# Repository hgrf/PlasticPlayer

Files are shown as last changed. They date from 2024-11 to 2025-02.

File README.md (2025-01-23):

# Plastic Player 3

This is a remake of [Plastic Player 2](https://brendandawes.com/projects/plasticplayer2) ([repo](https://github.com/brendandawes/PlasticPlayer)), an NFC based controller for Spotify. This isn't a step by step instructables style build guide but hopefully there's enough information here to build your own version. Knowledge of building stuff like this, soldering and understanding Linux, software compilation and the like would be good.

## System overview

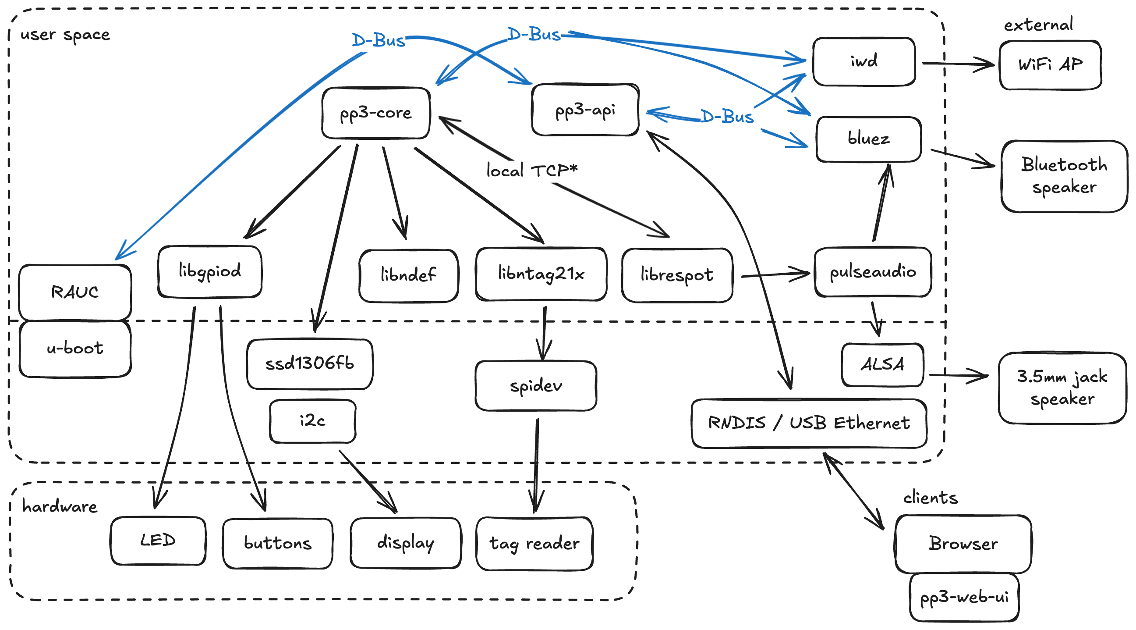
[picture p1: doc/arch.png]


*The TCP socket connection between pp3-core and librespot is a quick hack and should be replaced
by a clean D-Bus interface. [Spotifyd](https://github.com/Spotifyd/spotifyd) provides a D-Bus
media player interface and also uses `librespot` for playback, but it does not use an up-to-date
version of `librespot`...

## Materials

* **Raspberry Pi 4B** | [ CAD ](https://grabcad.com/library/raspberry-pi-4-model-b-1) | [ Amazon ](https://www.amazon.fr/dp/B07TGBLK33/)
* **128 x 64 I2C OLED**, [ CAD ](https://grabcad.com/library/arduino-0-91-0-96-inch-oled-1) | [ Amazon ](https://www.amazon.fr/dp/B0CN96XB5Y)
  NOTE: There are similar OLED modules with slightly different dimensions, e.g.:
  * https://grabcad.com/library/ssd1306-oled-display-128x64-1
  * https://grabcad.com/library/i2c-0-96-oled-ssd1306-display-1
  * https://grabcad.com/library/display-oled-ssd1306-de-0-96-1
  * Even when ordering twice from the same supplier (Amazon Link above), you can end up with 21 vs. 22 mm horizontal screw spacing
* [ **Joy-IT RFID module** ](https://joy-it.net/en/products/SBC-RFID-RC522) | [ CAD ](https://grabcad.com/library/rfid-rc5222-1) | [ Amazon ](https://www.amazon.fr/dp/B07B3N1WTL)
  * _TODO_: here too it seems the screw spacing does not 100% correspond
* 2 x **Sanwa Arcade Buttons** | [ CAD ](https://grabcad.com/library/sanwa-obsf-24-arcade-button-1) | [ Amazon ](https://www.amazon.fr/dp/B075DCB7LT)
* **NFC Stickers** | [ Amazon ](https://www.amazon.fr/dp/B0BVFM8YVD)
* 3D printed enclosure and slides (available on this repo)
* **screws**
  * display screws: 4x M1.7*5 PA Phillips self-tapping screw
  * Raspberry Pi screws: 4x M2*4
  * RF tag reader screw: 2x M3*4
  * case screws: 3x M3*8
* **magnets**
  * 2x Neodyme magnet 6x2 mm
  * 2x Neodyme magnet 3x2 mm
* **rubber feet** | e.g. cylindrical 8.5x2 mm [Amazon](https://www.amazon.fr/dp/B09KTCFC1L)
* a Spotify Premium account

## Hardware

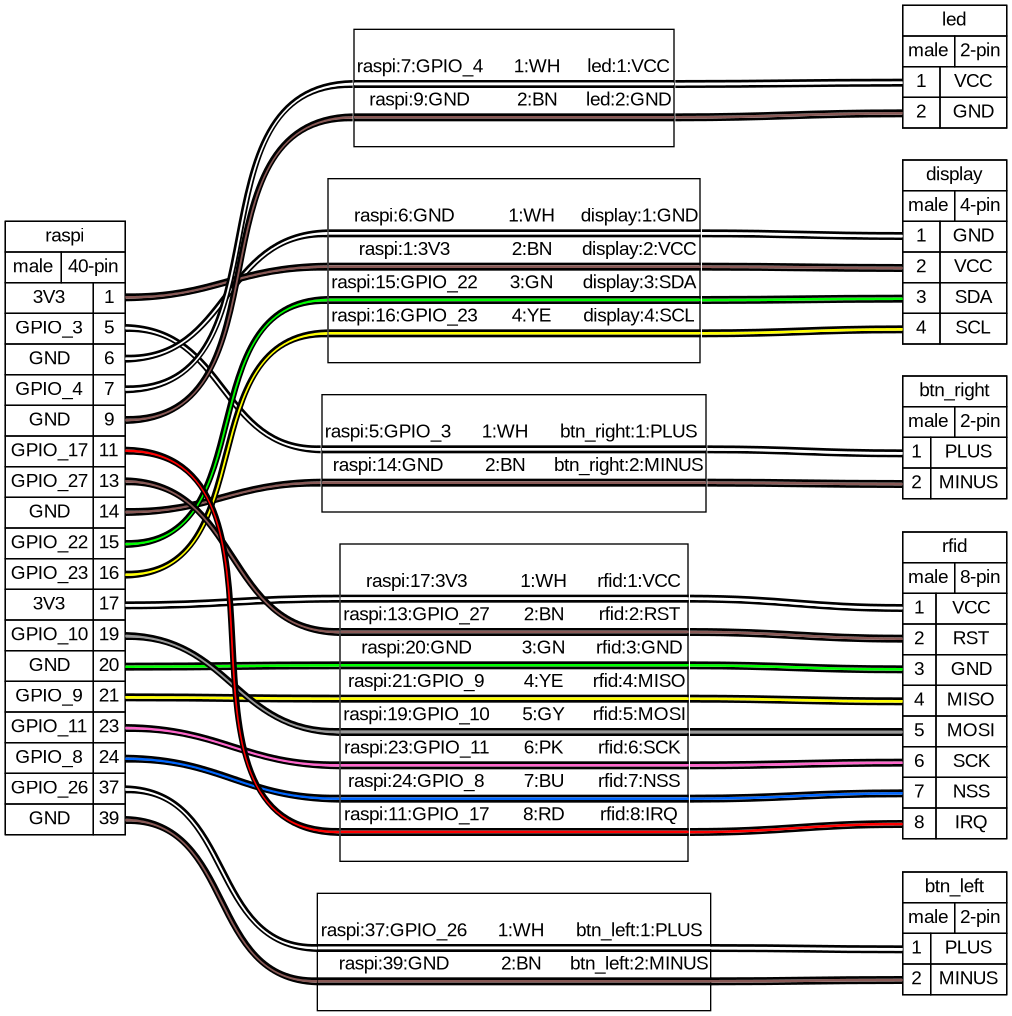
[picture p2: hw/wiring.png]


## Building

### Setting up buildroot

```sh
docker build -t buildroot docker
docker run --rm -it -v ${PWD}:/workspace buildroot bash
make -C buildroot/ BR2_EXTERNAL=../br-external O=../output raspberrypi4-64-rauc_defconfig
cd br-external && ./openssl-ca.sh
```

The last line generates an OpenSSL certificate and signing key for RAUC firmware updates.
Note that you can only use the firmware update feature if the new firmware was signed with
the same key as the old firmware.

If you want to connect to the Plastic Player via SSH, put your public key in the `ssh-keys`
directory.

### Building on macOS

On macOS, you might run into two problems:

* `chmod: changing permissions of ...: Permission denied`: In Docker Desktop, go to Settings
  -> General -> Choose file sharing implementation for your containers -> gRPC FUSE (instead
  of VirtioFS)
* `undefined reference to __lll_lock_wake_private` and possibly other build errors in glibc:
  Put your build folder in a case-sensitive file system, see:
  * https://brianboyko.medium.com/a-case-sensitive-src-folder-for-mac-programmers-176cc82a3830
  * https://stackoverflow.com/questions/73417071/glibc-compilation-error-undefined-reference-to-lll-lock-wait-private
  * https://github.com/riscv-collab/riscv-gnu-toolchain/issues/742#issuecomment-1061055030

### Building the image

```sh
docker run --rm -it -v ${PWD}:/workspace buildroot bash
make -C output/ VERSION=<PUT VERSION HERE>
```

## Developing

### SSH config

```
Host pp3
    HostName 10.42.0.1
    User user
    IdentityFile ~/.ssh/id_ed25519
    StrictHostKeyChecking=no
    UserKnownHostsFile=/dev/null
```

### Syncing the web app

```sh
rsync --rsync-path="sudo rsync" -avh --delete web_ui/build/web/ pp3:/usr/html
```

## Appendix

### Wiring

```sh
docker run --rm -it -v ${PWD}:/workspace buildroot /venv/bin/wireviz -f p wiring.yml
```

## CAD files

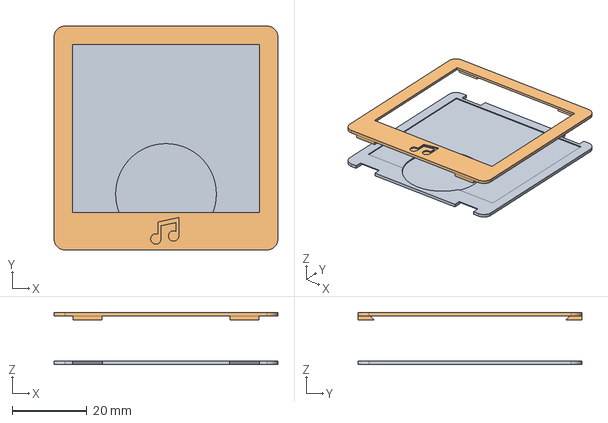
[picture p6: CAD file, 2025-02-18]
hw/plastic.FCStd
60.0 x 60.0 x 14.0 mm
Back
Front

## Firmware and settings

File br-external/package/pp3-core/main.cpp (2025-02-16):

#include <algorithm>
#include <cstdint>
#include <iostream>
#include <signal.h>

#include <ndef-lite/message.hpp>

#include "librespot.h"
#include "tagreader.h"
#include "ui.h"
#include "wifistatus.h"

static bool g_is_running = true;
static char stdout_buffer[1024];
static char stderr_buffer[1024];
static std::string g_current_uri;

static void signal_handler(int signum) {
    g_is_running = false;
}

static void load_uri(const std::string& uri) {
    const std::string base_uri = "https://open.spotify.com/";
    if (uri.substr(0, base_uri.length()) != base_uri) {
        std::cout << "URI does not start with " << base_uri << std::endl;
        return;
    }

    if (uri == g_current_uri) {
        return;
    }
    g_current_uri = uri;

    ui_led_on();
    std::string cmd = "load spotify:" + uri.substr(base_uri.length());
    std::replace(cmd.begin(), cmd.end(), '/', ':');
    std::cout << "cmd: " << cmd << std::endl;
    librespot_send_cmd(cmd.c_str(), false);
}

static void ndef_msg_cb(uint8_t *raw_msg, unsigned int len) {
    NDEFMessage msg;
    try {
        msg = NDEFMessage::from_bytes(std::vector<uint8_t>(raw_msg, raw_msg + len), 0);
    } catch (const std::exception& e) {
        std::cout << "failed to parse NDEF message: " << e.what() << std::endl;
        return;
    }

    std::cout << "NDEF message has " << msg.record_count() << " records" << std::endl;
    if (msg.record_count() > 0) {
        // c.f. https://github.com/hgrf/NDEF/commit/4c3133f6830fbe595c937db7a17c7a65eb487a82
        // c.f. https://github.com/hgrf/NDEF/commit/e035efd38d2deb2f6b94301faa5937c59c1dba61
        // c.f. https://www.oreilly.com/library/view/beginning-nfc/9781449324094/ch04.html
        // c.f. https://www.oreilly.com/library/view/beginning-nfc/9781449324094/apa.html
        // c.f. https://berlin.ccc.de/~starbug/felica/NFCForum-SmartPoster_RTD_1.0.pdf
        const auto &rec = msg.record(0);
        if (rec.type().name() == "U") {
            auto uri = msg.record(0).get_uri_protocol() + msg.record(0).get_uri();
            std::cout << "Record 1 URI: " << uri << std::endl;
            load_uri(uri);
        } else if (rec.type().name() == "Sp") {
            auto sp_msg = NDEFMessage::from_bytes(rec.payload(), 0);
            if (sp_msg.is_valid()) {
                std::cout << "Record 1 Smart Poster is valid and has " << sp_msg.record_count() << " records" << std::endl;
                if (sp_msg.record_count() > 0) {
                    const auto &sp_rec = sp_msg.record(0);
                    if (sp_rec.type().name() == "U") {
                        auto uri = sp_msg.record(0).get_uri_protocol() + sp_msg.record(0).get_uri();
                        std::cout << "Record 1 Smart Poster URI: " << uri << std::endl;
                        load_uri(uri);
                    } else {
                        std::cout << "Record 1 Smart Poster type: " << sp_rec.type().name() << std::endl;
                    }
                }
            }
        } else {
            std::cout << "Record 1 type: " << rec.type().name() << std::endl;
        }
    }
}

static void tag_removed_cb(void) {
    ui_led_off();
    g_current_uri.clear();
    librespot_send_cmd("pause", false);
}

int main(int argc, char *argv[]) {
    int res;

    signal(SIGINT, signal_handler);

    setvbuf(stdout, stdout_buffer, _IOLBF, sizeof(stdout_buffer));
    setvbuf(stderr, stderr_buffer, _IOLBF, sizeof(stderr_buffer));

    res = tag_reader_init(ndef_msg_cb, tag_removed_cb);
    if (res != 0) {
        return 1;
    }

    res = ui_init();
    if (res != 0) {
        tag_reader_deinit();
        return 1;
    }

    res = librespot_init();
    if (res != 0) {
        ui_deinit();
        tag_reader_deinit();
        return 1;
    }

    while(g_is_running) {
        ui_process();
    }

    librespot_deinit();

    ui_deinit();

    tag_reader_deinit();
    
    return 0;
}

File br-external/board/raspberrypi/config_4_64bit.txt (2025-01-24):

# For more options and information see
# http://rpf.io/configtxt
# Some settings may impact device functionality. See link above for details

# uncomment if you get no picture on HDMI for a default "safe" mode
#hdmi_safe=1

# uncomment the following to adjust overscan. Use positive numbers if console
# goes off screen, and negative if there is too much border
#overscan_left=16
#overscan_right=16
#overscan_top=16
#overscan_bottom=16

# uncomment to force a console size. By default it will be display's size minus
# overscan.
#framebuffer_width=1280
#framebuffer_height=720

# uncomment if hdmi display is not detected and composite is being output
#hdmi_force_hotplug=1

# uncomment to force a specific HDMI mode (this will force VGA)
#hdmi_group=1
#hdmi_mode=1

# uncomment to force a HDMI mode rather than DVI. This can make audio work in
# DMT (computer monitor) modes
#hdmi_drive=2

# uncomment to increase signal to HDMI, if you have interference, blanking, or
# no display
#config_hdmi_boost=4

# uncomment for composite PAL
#sdtv_mode=2

#uncomment to overclock the arm. 700 MHz is the default.
#arm_freq=800

# Uncomment some or all of these to enable the optional hardware interfaces
#dtparam=i2c_arm=on
#dtparam=i2s=on
#dtparam=spi=on

# Uncomment this to enable infrared communication.
#dtoverlay=gpio-ir,gpio_pin=17
#dtoverlay=gpio-ir-tx,gpio_pin=18

# Additional overlays and parameters are documented /boot/overlays/README

# Enable audio (loads snd_bcm2835)
dtparam=audio=on

# Automatically load overlays for detected cameras
camera_auto_detect=1

# Automatically load overlays for detected DSI displays
display_auto_detect=1

# Enable DRM VC4 V3D driver
dtoverlay=vc4-kms-v3d
max_framebuffers=2

# Disable compensation for displays with overscan
disable_overscan=1

[cm4]
# Enable host mode on the 2711 built-in XHCI USB controller.
# This line should be removed if the legacy DWC2 controller is required
# (e.g. for USB device mode) or if USB support is not required.
otg_mode=1

[all]

[pi4]
# Run as fast as firmware / board allows
arm_boost=1

[all]

# End of the default Raspberry Pi config.txt file from:
# https://github.com/RPi-Distro/pi-gen/blob/master/stage1/00-boot-files/files/config.txt

# Load U-Boot instead of Linux
kernel=u-boot.bin

# Enable 64-bit support
arm_64bit=1

# fixes rpi (3B, 3B+, 3A+, 4B and Zero W) ttyAMA0 serial console
dtoverlay=miniuart-bt

# Enable watchdog, system will reset if U-Boot and Linux do not boot within 16 seconds
# Requires fairly recent RPi Firmware:
# https://github.com/raspberrypi/firmware/issues/1651
# Comment this line if you expect to be able to use the U-Boot command prompt!
dtparam=watchdog

gpio=4=op,dh

# Enable early debugging info
uart_2ndstage=1

dtoverlay=i2c-gpio,i2c_gpio_sda=22,i2c_gpio_scl=23

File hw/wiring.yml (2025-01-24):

connectors:
  raspi:
    subtype: male
    pincount: 40
    pins:      [  1,      5,   6,      7,   9,      11,      13,  14,      15,      16,  17,      19,  20,     21,      23,     24,      37,  39]
    pinlabels: [3V3, GPIO_3, GND, GPIO_4, GND, GPIO_17, GPIO_27, GND, GPIO_22, GPIO_23, 3V3, GPIO_10, GND, GPIO_9, GPIO_11, GPIO_8, GPIO_26, GND]
  btn_left:
    subtype: male
    pinlabels: [PLUS, MINUS]
  btn_right:
    subtype: male
    pinlabels: [PLUS, MINUS]
  display:
    subtype: male
    pinlabels: [GND, VCC, SDA, SCL]
  rfid:
    subtype: male
    pinlabels: [VCC, RST, GND, MISO, MOSI, SCK, NSS, IRQ]
  led:
    subtype: male
    pinlabels: [VCC, GND]

cables:
  W1:
    show_name: false
    show_wirecount: false
    color_code: DIN
    wirecount: 2

  W2:
    show_name: false
    show_wirecount: false
    color_code: DIN
    wirecount: 2

  W3:
    show_name: false
    show_wirecount: false
    color_code: DIN
    wirecount: 4

  W4:
    show_name: false
    show_wirecount: false
    color_code: DIN
    wirecount: 8

  W5:
    show_name: false
    show_wirecount: false
    color_code: DIN
    wirecount: 2

connections:
  -
    - raspi: [37, 39]
    - W1: [1, 2]
    - btn_left: [1, 2]

  -
    - raspi: [5, 14]
    - W2: [1, 2]
    - btn_right: [1, 2]

  -
    - raspi: [6, 1, 15, 16]
    - W3: [1-4]
    - display: [1-4]

  -
    - raspi: [17, 13, 20, 21, 19, 23, 24, 11]
    - W4: [1-8]
    - rfid: [1-8]

  -
    - raspi: [7, 9]
    - W5: [1, 2]
    - led: [1, 2]

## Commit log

2024-11-05 add br2rauc
    repo: https://github.com/cdsteinkuehler/br2rauc
    SHA: 3b9b45e78fed462aecbd0a0de4c02486989b401d
    not added as submodule because I am going to change these files a lot
    [config_4_64bit.txt, config_5.txt, config_cm4io_64bit.txt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]
2024-11-15 USB: set up RNDIS ethernet gadget
    [config_4_64bit.txt]
2024-11-16 u-boot: enable software I2C
    u-boot does not have a driver for the BCM2711 I2C peripheral,
    but we can use the generic software I2C as a workaround and
    tell the Raspberry Pi firmware to apply the corresponding
    DT overlay.
    [config_4_64bit.txt]
2024-11-16 u-boot: add splash screen on SSD1306
    [genbootfs-raspberrypi4-64.cfg]
2024-11-23 remove unsupported boards
    [config_5.txt, config_cm4io_64bit.txt, config_default.txt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]
2024-11-23 rename br2rauc folder
    [config_4_64bit.txt, genbootfs-raspberrypi4-64.cfg, genimage.cfg]
2024-11-23 add latest CAD model
2024-11-30 add ntag21x driver
    [config_4_64bit.txt]
2024-12-22 enable SSD1306 devicetree overlay
    [config_4_64bit.txt]
2024-12-22 enable user access to GPIO and SPI
2024-12-25 add ncurses UI and button control
2024-12-30 web ui: show RAUC slot status, enable file upload
2024-12-30 web ui: add reboot button
2025-01-01 u-boot / rauc: remove rescue partition
    [genimage.cfg]
2025-01-01 firmware config: switch on LED
    [config_4_64bit.txt]
2025-01-01 hardware: add wiring diagram
2025-01-01 genimage: move extended partition to slot 3
    Without the rescue partition, rootfs.0 ends up
    in partition 3 and rootfs.1 in partition 5 (so
    the mapping to partitions 4 and 5 was wrong).
    Instead of using partitions 3 and 5, I prefer to
    move the extended partition to slot 3, so that
    the two rootfs partitions are in slot 5 and 6,
    like they were when there was still a rescue
    partition.
    [genimage.cfg]
2025-01-01 uboot: switch off LED (switched on by firmware)
2025-01-03 pp3-main: switch on LED while tag detected
2025-01-05 enable bluetooth and switch to pulseaudio
2025-01-06 DT switcheroo: use UART0 (PL011) for Bluetooth
    [config_4_64bit.txt, genbootfs-raspberrypi4-64.cfg]
2025-01-12 doc: update BOM
2025-01-13 Bluetooth: filter discovery by A2DP audio sink
2025-01-19 Bluetooth: device list and connection with hw-ui
2025-01-21 docker: add deps for wireviz
2025-01-21 Bluetooth: remove superfluous dir, comment out default opt
    NOTE: interestingly, main.conf has to exist, otherwise the
    controller is not powered on
2025-01-24 implement power-on from right button
    This feature uses the wake-up mechanism from the Raspberry Pi
    firmware. The firmware reboots into a "halt" state when the
    boot partition ID indicated in the watchdog RSTS register is
    set to 63. It can be woken up by a negative edge on GPIO3.
    In order for this to be triggered by one of our buttons, we
    change the pinout to connect the button to GPIO3 and connect
    the display to I2C6 (it used to be on I2C1 which can no longer
    be used).
    [config_4_64bit.txt]
2025-01-26 pp3-core: add power off to menu
    also add missing sentinel value to menu items array
    [ui.c]
2025-02-05 CAD: update model
    * Chamfer009 from 0.8 -> 1.2 mm
    * Added cylinder and 3 mirrors to TopBottomScrewHoles for deeper display screw holes
    * moved "DisplayScrewSupport 3" 0.3 mm outwards
    * replaced "DisplayScrewSupper 3" (Tube) by Cylinder015
    * increased Cylinder015 radius to 2 mm and decreased their height to 1.8 mm
    * added 0.3 mm chamfer to display screw holes
    * decreased window size by 1.4 mm in both directions
    * moved display closer to window
    * added 1 mm to front wall thickness
    * added space for magnet in top cover
    * removed inscription on back
    * removed offset of SliderHolderCut
    * reduced slideholder screw holes (Cylinder002 and Cylinder005) radius from 1.5 mm to 1.35 mm
    * moved top wall 1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
2025-02-15 pp3-core: ntag: skip lock TLV if present
    [main.cpp]
2025-02-15 libntag21x: expose mfrc522 driver handle (#3)
2025-02-15 pp3-core: read mfrc522 error register when search fails
    [main.cpp]
2025-02-16 pp3-core: correct error propagation from ntag21x_basic_search
    [main.cpp]
2025-02-16 pp3-core: avoid repeated readout of same tag
    This also fixes failure on every second call to ntag21x_basic_search().
    [main.cpp]
2025-02-16 pp3-core: rework tag reader with callbacks
    [main.cpp]
2025-02-18 CAD: add plastic model from dev branch
    (also recompute and apply corrections after update to FreeCAD 1.0)
    [plastic.FCStd]
2025-02-19 pp3-core: tag_reader: use all four pages read by the driver
2025-02-22 pp3-core: ui: correct button polling timeout to 200 ms
    [ui.c]
